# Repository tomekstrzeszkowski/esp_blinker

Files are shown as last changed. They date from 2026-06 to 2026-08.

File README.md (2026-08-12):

# Motivation

In recent years, there has been a significant rise in the usage of digital devices across all age brackets, whether for work or leisure. Various therapeutic and management approaches have been suggested to address this issue, encompassing optical, medical, and ergonomic interventions.

One common recommendation from clinicians is to take regular breaks to reduce digital eye strain. This advice often includes following the 20-20-20 rule, which suggests taking breaks to focus on an object at least 20 feet (6 meters) away for at least 20 seconds every 20 minutes.

This project serves as a reminder to perform these exercises by toggling your external device on and off, ideally accompanied by a light indicator.

# Hardware 

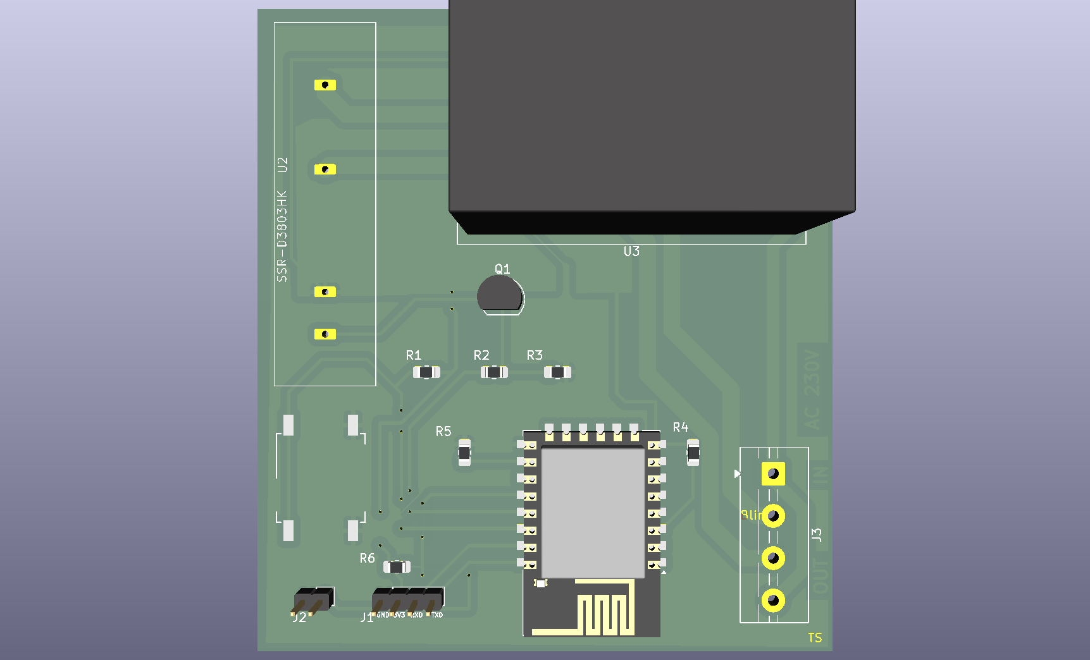
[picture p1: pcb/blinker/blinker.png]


## Electrical components and flashing
 - ESP8266

[PCB & Flashing](pcb/README.md)
 
# MQTT

## Home assistant

In devices & services add integration and search for MQTT. Add default integration.
In Apps, install app `Mosquitto broker`. Then go to config and add entry to logins.
Add new entry under MQTT and configure device, use `esp32/gpio/set` and switch component.

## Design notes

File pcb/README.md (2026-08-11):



# PIN out

## 4 Socket PINs (J1)

1 - GND
2 - 3V3
3 - GPIO 3 / RXD
4 - GPIO 1 / TXD

## 2 Socket PINs

1, 2 GPIO0 - Boot up PINS (J2)

# Wiring ConnectionsUSB-to-UART 

 - USB TX - Connect to GPIO3 (RXD) on the ESP 
 - USB RX - Connect to GPIO1 (TXD) on the ESP
 - GND - Connect adapter GND to ESP GND

Enter into flashing mode
 - GPIO0 - Connect to GND, just connect 1 with 2 togeter via jumper

# Flashing
 - Enter flashing mode (blue LED should flash once)
 - Follow your preffered flashing IDE

## VS Code and PlatformIO

 - On the bottom bar, select esp12e, ttyUSB0
 - Click PlatformIO upload

At this point you should see percentage progress and LED should flash in some intervals

## esptool and PlatformIO

 - Install requirements.txt, this should install esptool and PlatformIO
 - PlatformIO builds firmware in this location
```
blinker/.pio/build/esp12e/firmware.bin
```
 - Build `firmware.bin` (list available targets `pio run --list-targets`)

```
pio run -e esp12e
```
This should produce firmware in the location as above.

 - Flash
```
esptool --port /dev/ttyUSB0 write-flash 0x00000 blinker/.pio/build/esp12e/firmware.bin
```

For ESP32

```
esptool --port /dev/ttyUSB0 --chip esp32 write-flash 0x10000 firmware.bin
```

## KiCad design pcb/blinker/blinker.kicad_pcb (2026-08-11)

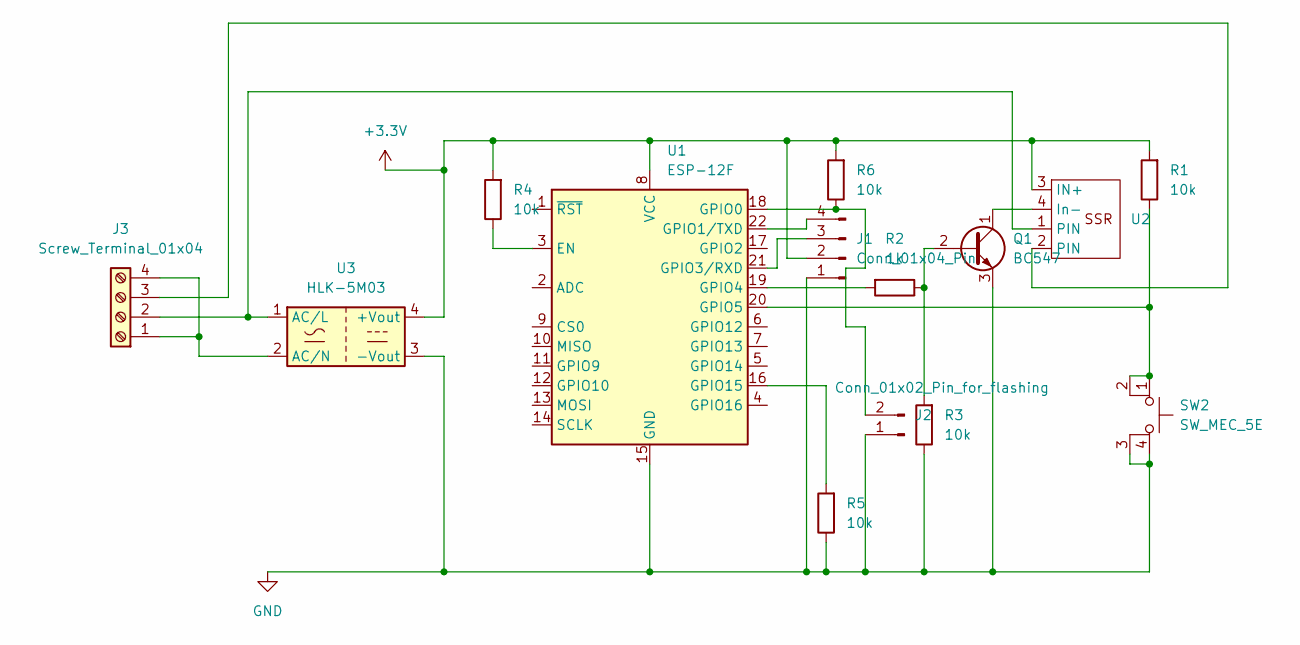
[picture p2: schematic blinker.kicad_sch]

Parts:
J1: Conn_01x04_Pin; PinHeader_1x04_P2.00mm_Vertical
J2: Conn_01x02_Pin_for_flashing; PinHeader_1x02_P2.00mm_Vertical
J3: Screw_Terminal_01x04; TerminalBlock_MaiXu_MX126-5.0-04P_1x04_P5.00mm
Q1: BC547; TO-92_Inline
R1, R3, R4, R5, R6: 10k; R_0805_2012Metric_Pad1.20x1.40mm_HandSolder
R2: 1k; R_0805_2012Metric_Pad1.20x1.40mm_HandSolder
SW2: SW_MEC_5E; SW_MEC_5GSH9
U1: ESP-12F; ESP-12E
U2: SSR-D3803HK
U3: HLK-5M03; Converter_ACDC_Hi-Link_HLK-5Mxx

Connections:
+3.3V: J1.2, R1.2, R4.2, R6.2, U1.8 (VCC), U2.3 (IN+), U3.4 (+Vout)
GND: J1.1, J2.1, Q1.3 (E), R3.1, R5.1, SW2.3 (K), SW2.4 (A), U1.15 (GND), U3.3 (-Vout)
unnamed: J1.3, U1.21 (GPIO3/RXD)
unnamed: J1.4, U1.22 (GPIO1/TXD)
unnamed: J2.2, R6.1, U1.18 (GPIO0)
unnamed: J3.1, J3.4, U3.2 (AC/N)
unnamed: J3.2, U2.1 (PIN), U3.1 (AC/L)
unnamed: J3.3, U2.2 (PIN)
unnamed: Q1.2 (B), R2.1, R3.2
unnamed: Q1.1 (C), U2.4 (In-)
unnamed: R4.1, U1.3 (EN)
unnamed: R2.2, U1.19 (GPIO4)
unnamed: R1.1, SW2.1, SW2.2, U1.20 (GPIO5)
unnamed: R5.2, U1.16 (GPIO15)

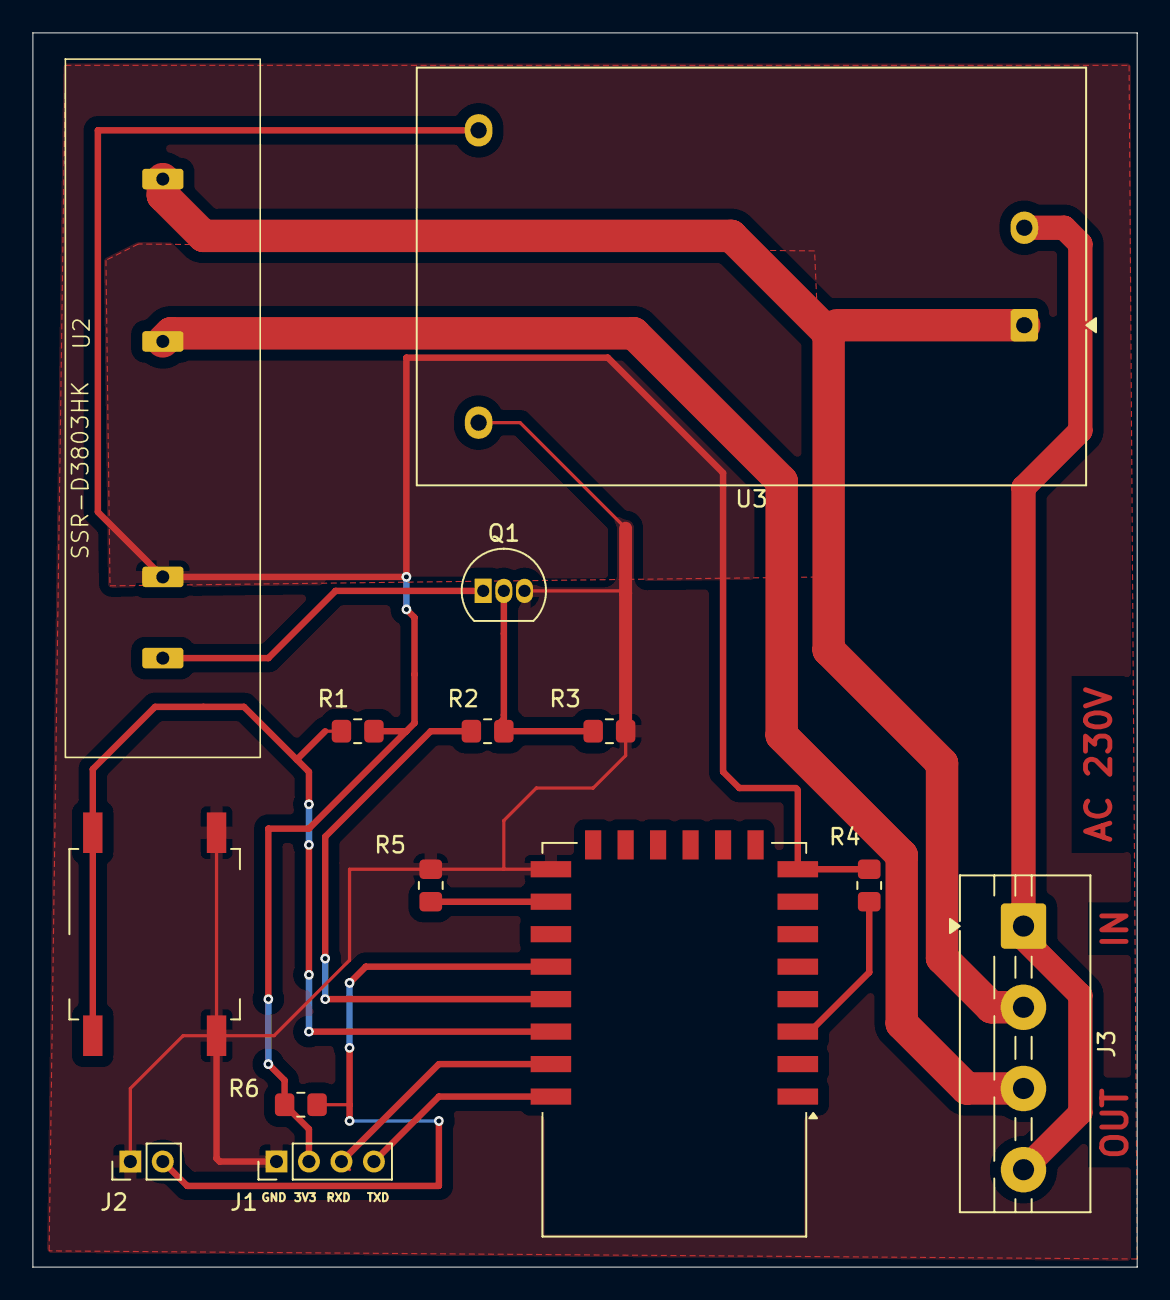
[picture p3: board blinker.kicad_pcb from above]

Board: 2 copper layers, 68.0 x 76.0 mm, 14 parts (0 on the bottom side), 14 nets.

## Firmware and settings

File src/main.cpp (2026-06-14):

#include <Arduino.h>
#include <blinker.h>
#include <job.h>
#include <button.h>
#include <connectivity.h>

#define LIGHT_CHANNEL 4
#define BUTTON_CHANNEL 5

Blinker blinker(LIGHT_CHANNEL);
Button button(BUTTON_CHANNEL);
Job job{blinker};


Connectivity connectivity(
    WIFI_SSID, WIFI_PASS, MQTT_HOST, MQTT_USER, MQTT_PASS,
    []() {
        job.switchDayMode();
    },
    []() -> bool {
      return digitalRead(LIGHT_CHANNEL) == LOW;
    }
);

void setup() {
  connectivity.setup();
  button.setup();
  job.setup();
  connectivity.waitForWifi();
  job.welcomeBlink();
}

void loop() {
  connectivity.tick();
  job.tick();
  if (button.isPressed) {
    button.isPressed = false;
    job.switchDayMode();
    connectivity.publishState(connectivity.getState());
  } 
  yield();
}

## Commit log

2026-06-06 Add button
2026-06-07 Publish correct state to MQTT
    [main.cpp]
2026-06-15 Generic MQTT props names, WDT feed preventing resets, Generic config
2026-06-22 Add ESP32dev, Add home assistant ESPHome builder script
2026-06-29 Add PCB
    [blinker.kicad_pcb, blinker.kicad_sch, blinker_backup.kicad_pcb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]
2026-07-14 Replace 0402 resistors with 2012 handSolder
    [blinker.kicad_pcb, blinker.kicad_sch]
2026-07-16 Update Relay pins
    [blinker.kicad_pcb]
2026-07-16 Change label pos on PCB
    [blinker.kicad_pcb]
2026-07-18 Update Relay footprint
    [blinker.kicad_pcb]
2026-07-26 Put PCB resistor in one line
    [blinker.kicad_pcb]
2026-08-08 Change to Converter_ACDC:HLK-5M03
    [blinker.kicad_pcb, blinker.kicad_sch]
2026-08-11 Add image
    [blinker.kicad_pcb]
2026-10-10 Update readme and attach compressed zip for jlcpcb
